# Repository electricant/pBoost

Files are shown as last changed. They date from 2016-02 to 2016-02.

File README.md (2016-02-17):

# pBoost (pico-Boost)
Boost converter from 5V to 9V or 12V (user selectable). 1A maximum current

## The Project
I needed a way to power a small WiFi router from the same power supply that
powers a raspberry pi (5V 2A) so this board is born.

The router I plan to use has a power supply rated for 9V and 500mA so this is
my target deisgn goal.

Since the output voltage of the conveter is set by a resistor ratio I decided
to add a jumper-selectable output voltage. 12V were chosen because sometimes
routers come with 12V 1A power supplies so this design should be upgrade-proof.

NOTE: actually the maximum output current for 12V operation is a little lower
than 500mA. So be careful to check the current draw of your device.

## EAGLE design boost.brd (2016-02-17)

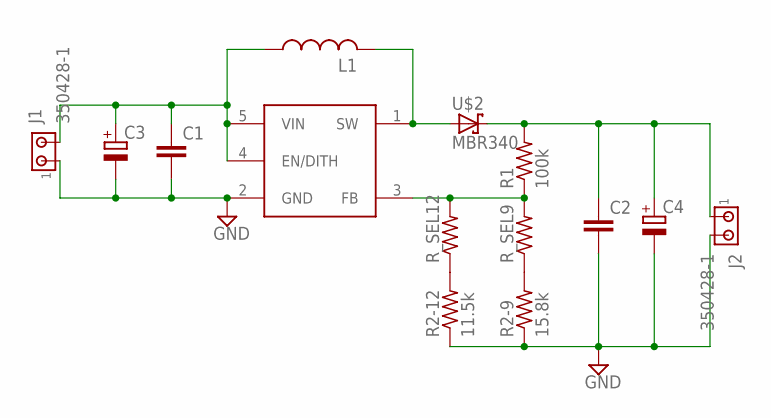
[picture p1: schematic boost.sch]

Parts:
C1, C2: C-EUC3216; C3216
C3, C4: CPOL-EUE1.8-4; E1,8-4
J1, J2: 350428-1
L1: L-US6000-XXX-RC; 6000-XXXX-RC
R1: 100k; M0805
R2-9: 15.8k; M0805
R2-12: 11.5k; M0805
R_SEL9, R_SEL12: R-US_R0402; R0402
U$1: MIC2250-2YD5; SOT23-5
U$2: MBR340; MBR340-V

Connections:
GND: C1.2, C2.2, C3.-, C4.-, J1.1, J2.2, R2-9.1, R2-12.1, U$1.2 (GND)
unnamed: L1.2, U$1.1 (SW), U$2.P$1 (A)
unnamed: R1.1, R_SEL9.2, R_SEL12.2, U$1.3 (FB)
unnamed: R2-12.2, R_SEL12.1
unnamed: R2-9.2, R_SEL9.1
VIN: C1.1, C3.+, J1.2, L1.1, U$1.4 (EN/DITH), U$1.5 (VIN)
VOUT: C2.1, C4.+, J2.1, R1.2, U$2.P$2 (C)

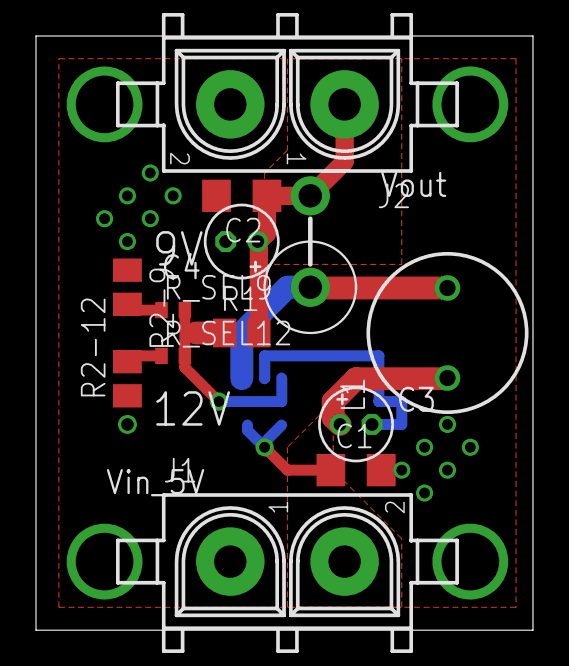
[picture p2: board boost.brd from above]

Board: 2 copper layers, 27.6 x 33.0 mm, 14 parts (1 on the bottom side), 7 nets.

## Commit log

2016-02-17 Add schematic and board drawings
    [boost.brd, boost.sch]
2016-02-17 Add generated gerber files
    [boost.drills.xln]
2016-02-17 Update readme with a note about maximum output current
